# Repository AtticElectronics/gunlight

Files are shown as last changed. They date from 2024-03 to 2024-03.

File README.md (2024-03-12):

# gunlight
YouTube에서 총으로 불을 끄는 영상 관련 코드 및 자료입니다.
이 자료는 제가 제작에 사용한 자료를 공유하는 것일 뿐, 프로젝트 완성 가이드라인은 아닙니다.
전기 전자 회로는 실사용에 적합하지 않음을 이해한 후 개선하여 사용하시길 당부드립니다.

# 제작 방법 및 팁
1. 소음기 제작


1) gunlight.3mf 파일로 3D 모델링을 출력합니다.
2) 조립 시, 소음기-내부지지.stl 파일에 LR44 배터리 홀더를 사진과 같은 위치에 두고 순간접착제로 부착합니다. 홈이 있어 위치 잡기가 수월합니다.
3) 소음기-내부지지.stl의 상단 부분에는 4개의 구멍이 있으며, 여기에 인서트(M2, 외경 3.2mm, 길이 4mm)를 삽입합니다.
4) 소음기-내부지지.stl의 하반부에는 채리스 스위치를 사진과 같은 방향으로 삽입합니다.
5) 소음기-내부지지.stl의 하단 부분에 소음기-연결소켓.stl을 연결하고, 공이.stl을 삽입합니다.
6) 레이저 5V 6mm 제품을 상단에 연결하고 볼트(M2 6mm)로 조인한 후 모든 전선을 직렬 스위치 방식으로 LR44의 상단 구리판에 납땜합니다.
7) 실리콘 테이프를 붙여 진동으로 배터리가 빠지지 않도록 한 다음 외부통27_1.stl을 끼워줍니다.

2. 플러그 제작
1) 회로는 다음과 같습니다. 낙뢰와 과전류로부터 보호하기 위해 MOV와 퓨즈를 추가한 일반적인 회로입니다.
2) 거버 파일은 업로드해 두었습니다.
3) 절대 제 자료를 신뢰해서 제작하지 마십시오. 화재, 감전의 위험이 있습니다.

3. 과녁 제작
1) temt6000이라는 광 트랜지스터를 5개 사용해서 아날로그 신호값을 읽어 측정하는 방식입니다.
2) deep sleep 모드에서 일정 논리 전압 이상으로 wake-up 시키는 방식으로, 배터리로 1년 이상 사용 가능은 하나, 측정 정확도 면에서 많은 반복 테스트를 요하기 때문에 쉽게 따라할 수 없음을 알리기에 이 방식은 공개하지 않기로 했습니다.
3) 임시로 배터리는 반나절 유지 가능하나 유선 전원으로 사용 시 안정적으로 사용 가능한 코드와 이에 맞는 회로를 업로드해 두었습니다.

# 사용 방식
1. 과녁에 MCU 없이 각 회로의 dip switch가 0000으로 설정한 뒤, 과녁과 플러그 간의 PH2.0 커넥터를 연결해서 유선으로 사용할 수 있습니다.
2. 플러그의 5V와 GND를 과녁의 MCU에 유선 연결하여 사용하는 방식은 안정적으로 동작하며, 배터리 없이 이상적입니다.
3. AAA 배터리를 사용하여 MCU에 전원을 공급하여 사용하는 방식은 추천하지 않습니다.

# 사용된 기타 부품들
1. RONGFENG E-08
2. RONGFENG SS-7B

# 개선 및 제안
과녁 회로를 ESP32의 deep sleep을 적용 가능하게 수정하면 매우 적은 전력으로 오래 사용 가능하지만, 그 과정이 프린트 방식 플라스틱 종류, 레이저 파워 등등 여러 요인에 따라 매우 민감하게 달라짐으로, 제작자가 개인적으로 테스트하여 시도해보시길 바랍니다.

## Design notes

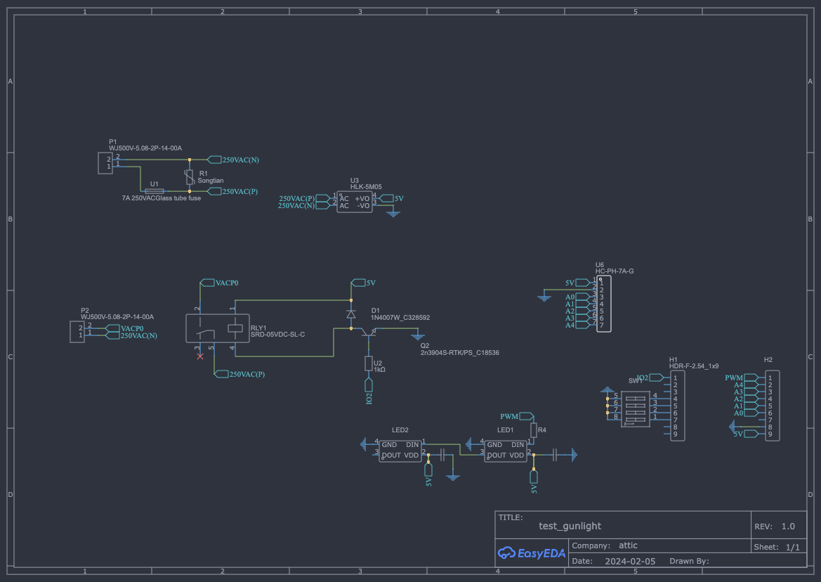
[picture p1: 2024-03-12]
pcb/plug/Schematic_espplug_2024-03-12.png

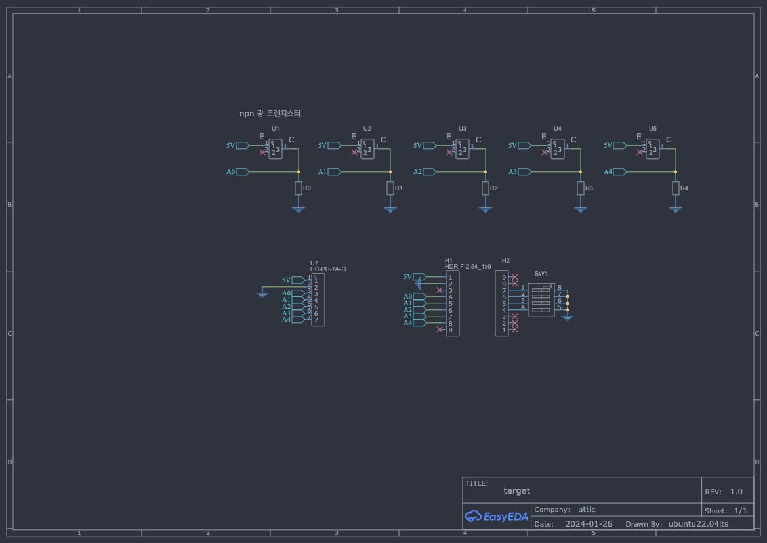
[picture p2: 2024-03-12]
pcb/target/Schematic_target_2024-03-12.png

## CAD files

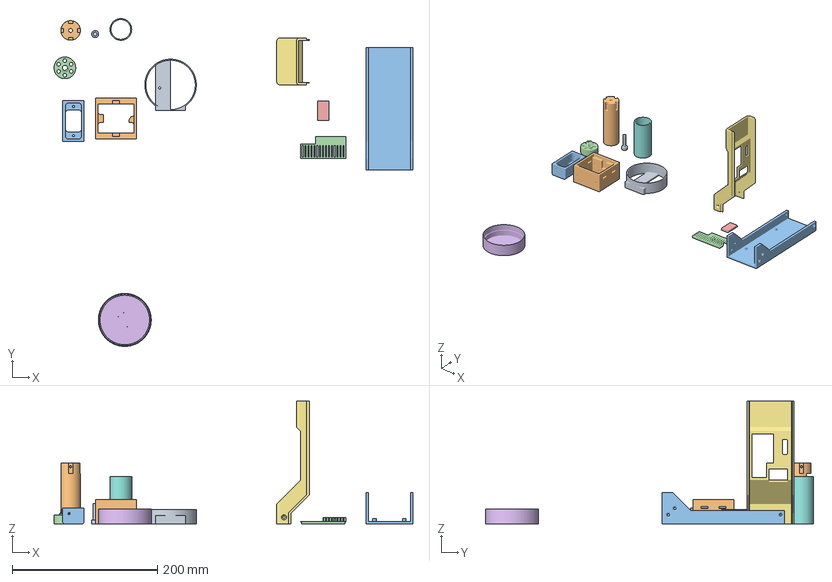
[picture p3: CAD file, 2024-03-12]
3d/gunlight.3mf
494.1 x 451.3 x 168.8 mm
타겟-뒤뚤림.stl
케이스-출력.stl
케이스-입력.stl
cover1.stl
cover2.stl
앞001
top.stl
외부통27_1.stl
laser-Body003.stl
소음기-내부지지.stl
케이스-하판.stl
소음기-연결소켓.stl

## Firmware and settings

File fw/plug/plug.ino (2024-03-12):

#include <Adafruit_NeoPixel.h>
#include "CircularQueue.h"
#include <esp_now.h>
#include <WiFi.h>

#define SAMPLE_LEN 5
#define K 30

typedef struct struct_message
{
    char msg[32];
    int channel;
} struct_message;

struct_message myData;
uint8_t broadcastAddress[] = {0xFF, 0xFF, 0xFF, 0xFF, 0xFF, 0xFF};
bool light_toggle = false;

CircularQueue q1(SAMPLE_LEN), q2(SAMPLE_LEN), q3(SAMPLE_LEN), q4(SAMPLE_LEN), q5(SAMPLE_LEN);
Adafruit_NeoPixel strip = Adafruit_NeoPixel(2, 6, NEO_GRB + NEO_KHZ800);
int channel = 0;

void (*loopFunction)();

void setupHardware();
void initializeNeoPixel();
void setup()
{
    Serial.begin(115200);
    delay(1000);

    setupHardware();
    initializeNeoPixel();

    channel = digitalRead(13) * 8 + digitalRead(12) * 4 + digitalRead(11) * 2 + digitalRead(10) * 1;
    // channel = 1; // For testing, override channel value

    toggleLight();
    if (channel != 0)
    {
        loopFunction = wirelessLoop;
        WiFi.mode(WIFI_STA);
        if (esp_now_init() != ESP_OK)
        {
            Serial.println("Error initializing ESP-NOW");
            return;
        }
        esp_now_register_recv_cb(OnDataRecv);
    }
    else
    {
        loopFunction = wireLoop;
    }
}

void setupHardware()
{
    pinMode(13, INPUT_PULLUP);
    pinMode(12, INPUT_PULLUP);
    pinMode(11, INPUT_PULLUP);
    pinMode(10, INPUT_PULLUP);

    pinMode(1, INPUT);
    pinMode(2, INPUT);
    pinMode(3, INPUT);
    pinMode(4, INPUT);
    pinMode(5, INPUT);

    pinMode(7, OUTPUT);
}

void initializeNeoPixel()
{
    strip.begin();
    strip.show();
    showRainbow(3000); // 전체 무지개 표현을 3초간 진행
}

void loop()
{
    loopFunction();
}

void wireLoop()
{
    int a1 = 0, a2 = 0, a3 = 0, a4 = 0, a5 = 0;
    for (int i = 0; i < 10; i++)
    {
        a1 += analogRead(1);
        a2 += analogRead(2);
        a3 += analogRead(3);
        a4 += analogRead(4);
        a5 += analogRead(5);
    }
    a1 /= 10;
    a2 /= 10;
    a3 /= 10;
    a4 /= 10;
    a5 /= 10;

    q1.enqueue(a1);
    q2.enqueue(a2);
    q3.enqueue(a3);
    q4.enqueue(a4);
    q5.enqueue(a5);

    if (q1.hasIncreaseDecreaseEdge(K) || q2.hasIncreaseDecreaseEdge(K) ||
        q3.hasIncreaseDecreaseEdge(K) || q4.hasIncreaseDecreaseEdge(K) ||
        q5.hasIncreaseDecreaseEdge(K))
    {
        Serial.println("Pattern Detected");
        toggleLight();
        q1.clear();
        q2.clear();
        q3.clear();
        q4.clear();
        q5.clear();
    }
}

void wirelessLoop()
{
    delay(1000);
}

void toggleLight()
{
    light_toggle = !light_toggle;
    digitalWrite(7, light_toggle ? HIGH : LOW); // GPIO 7번 핀 상태를 light_toggle 값에 따라 변경

    // light_toggle 값에 따라 LED 색상을 변경: false일 때 빨간색, true일 때 초록색
    uint32_t redColor = strip.Color(50, 0, 0);   // 빨간색
    uint32_t greenColor = strip.Color(0, 50, 0); // 초록색

    strip.setPixelColor(0, light_toggle ? greenColor : redColor);
    strip.setPixelColor(1, light_toggle ? greenColor : redColor);
    strip.show();
}

void OnDataRecv(const uint8_t *mac, const uint8_t *incomingData, int len)
{
    memcpy(&myData, incomingData, sizeof(myData));
    Serial.print("Bytes received: ");
    Serial.println(len);
    Serial.print("Message: ");
    Serial.println(myData.msg);
    Serial.print("Number: ");
    Serial.println(myData.channel);
    if (myData.channel == channel && strcmp(myData.msg, "toggle") == 0)
    {
        toggleLight();
    }
}
// 무지개 색상을 표현하는 함수
void showRainbow(unsigned long wait)
{
    unsigned long startTime = millis();
    unsigned long currentTime;

    do
    {
        currentTime = millis();
        // 현재 시간에 따라 무지개 색상의 위치 계산
        float progress = float(currentTime - startTime) / wait;
        int rainbowColorPosition = int(progress * 256 * 5) % 256; // 256 색상을 5번 반복

        for (int i = 0; i < strip.numPixels(); i++)
        {
            // 픽셀별로 색상 설정
            strip.setPixelColor(i, Wheel(rainbowColorPosition));
        }
        strip.show();

        // 다음 색상으로 넘어가기 전에 약간 대기
        delay(20);
    } while (currentTime - startTime < wait);
}

// Wheel 함수: 색상 휠에서 색상을 선택 (0~255 범위의 색상)
uint32_t Wheel(byte WheelPos)
{
    WheelPos = 255 - WheelPos;
    if (WheelPos < 85)
    {
        return strip.Color(255 - WheelPos * 3, 0, WheelPos * 3);
    }
    else if (WheelPos < 170)
    {
        WheelPos -= 85;
        return strip.Color(0, WheelPos * 3, 255 - WheelPos * 3);
    }
    else
    {
        WheelPos -= 170;
        return strip.Color(WheelPos * 3, 255 - WheelPos * 3, 0);
    }
}
